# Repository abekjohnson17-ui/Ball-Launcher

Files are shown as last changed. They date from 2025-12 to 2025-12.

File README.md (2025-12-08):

Ping Pong Ball Launcher

What does it do?

This project is a ball launcher that has a closed-loop feedback system. There are three main things that the project does:
1. Calculate the velocity after each shot to dial in the accuracy on the next shot.
2. Often times ping pong can have a wide variety of spin on the ball, this machine can change the spin of the ball at launch.
3. Randomly decide where the next shot will be from left to right.

Motivation:

I am an avid tennis player and a student at the University at Buffalo studying Mechanical Engineering. I wanted to make a tennis ball launcher but the motors and components would be out of my budget, so I decided to scale it down to a ping pong ball launcher. 
I have used tennis ball launchers before and one thing that they can do is they can put variable spin on the ball to simulate a real game. This is a major feature I want to encorporate into my project. Essentially, the two robots are the same just scaled differently.

BOM:



Link to BOM: 

https://docs.google.com/spreadsheets/d/1TKzZSILnyTzFo4eQHcQ44TPMbz68pp8OG-lISy_ujTU/edit?gid=0#gid=0

STL Files are located under the src folder -> STL Files

Wiring:



What is Each Part Responsible for?
- 12V MAX 300 RPM DC Motors >> Spin the wheels to launch the balls.
- 6V MAX 5 RPM DC Motors >> Spin auger feeding mechanism.
- 20KG Servo Motor >> Turn machine left to right.
- Hall Effect Sensors >> Used to determine spin and RPM of motors.
- Laser Reciever Sensors >> Used to calculate exit velocity of the ball and make the next shot more accurate.
- L293D Motor Driver >> Allows for variable speed control of the motors.

Limitations:

1. The motors do not spin fast enough to launch the ball at a decent distance, I should have used motors that spin at much higher RPM. To get around this with what I had I used a gear ratio to increase speed.
2. The auger feeding mechanism will drop 2-3 balls at a time. To fix this I can add dividers along the length of the auger to drop one ball at a time.
3. The servo that turns the machine from left to right will jam sometimes. I should have made the attachment system more aligned with the axis.

Pictures:







Link to YouTube Video of Velocity Calculation Demo:

[https://studio.youtube.com/video/sxxTJT0Kazk/edit](https://youtube.com/shorts/sxxTJT0Kazk)

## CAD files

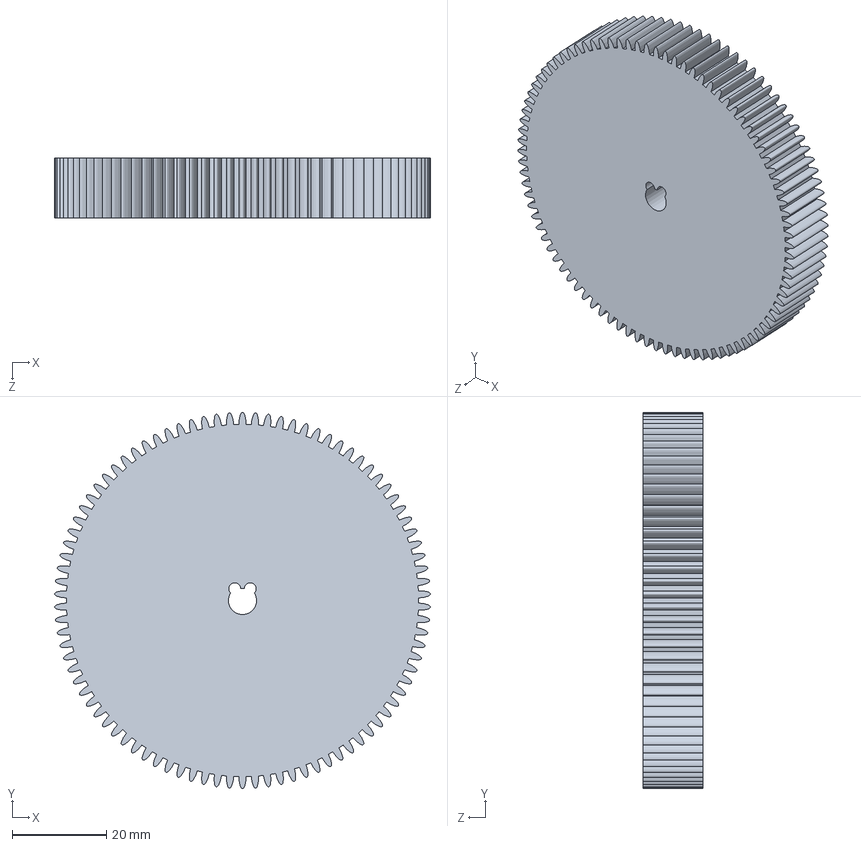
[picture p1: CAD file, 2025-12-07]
src/STL Files/MAE476 PROJECT V2/GEARBOTTOM.SLDPRT
80.0 x 80.0 x 12.7 mm

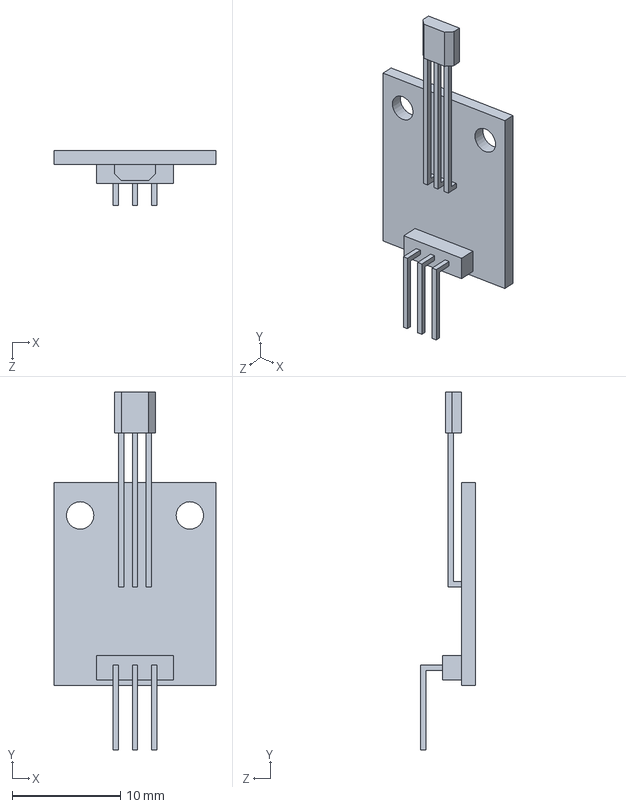
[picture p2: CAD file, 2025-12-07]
src/STL Files/MAE476 Project/HALLEFFECT.SLDPRT
15.0 x 33.1 x 5.08 mm

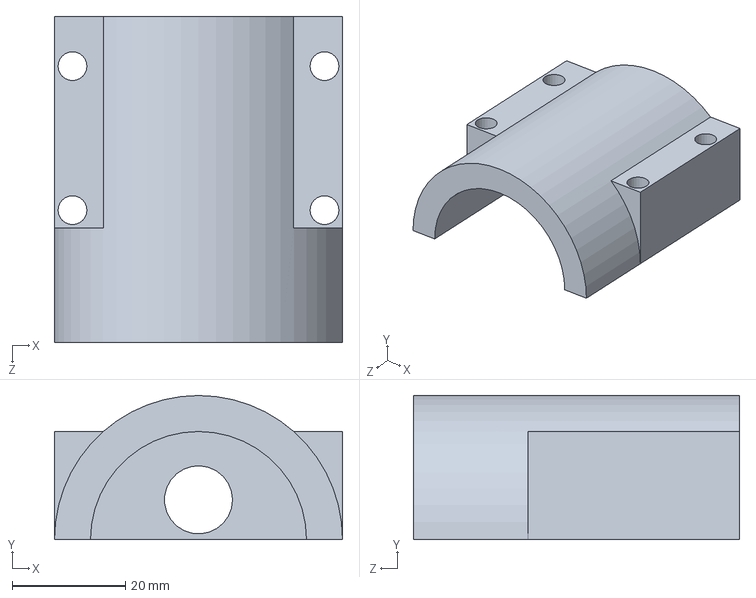
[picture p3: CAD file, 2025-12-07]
src/STL Files/MAE476 PROJECT V2/12VMOUNT.SLDPRT
50.8 x 25.4 x 57.6 mm

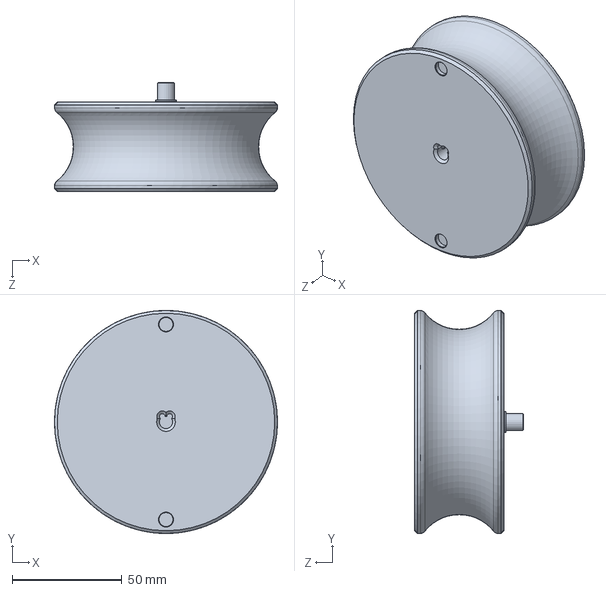
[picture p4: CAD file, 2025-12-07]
src/STL Files/MAE476 Project/WHEEL.SLDPRT
101.6 x 101.6 x 49.5 mm

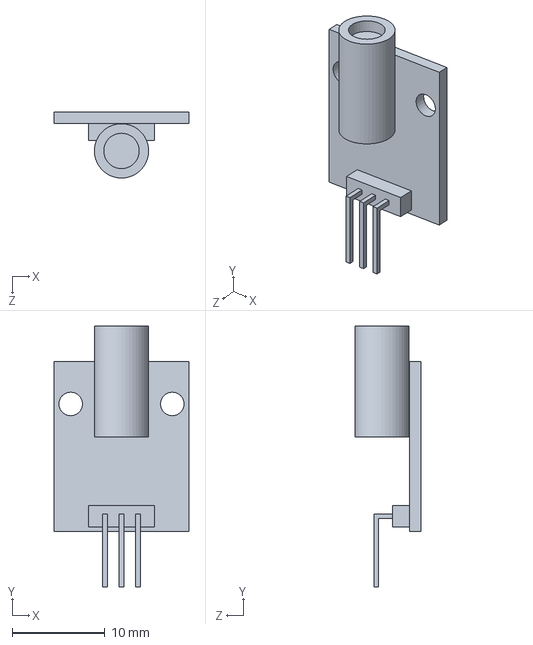
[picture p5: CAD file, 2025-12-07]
src/STL Files/MAE476 Project/LAZEREMITTER.SLDPRT
14.5 x 28.1 x 7.11 mm

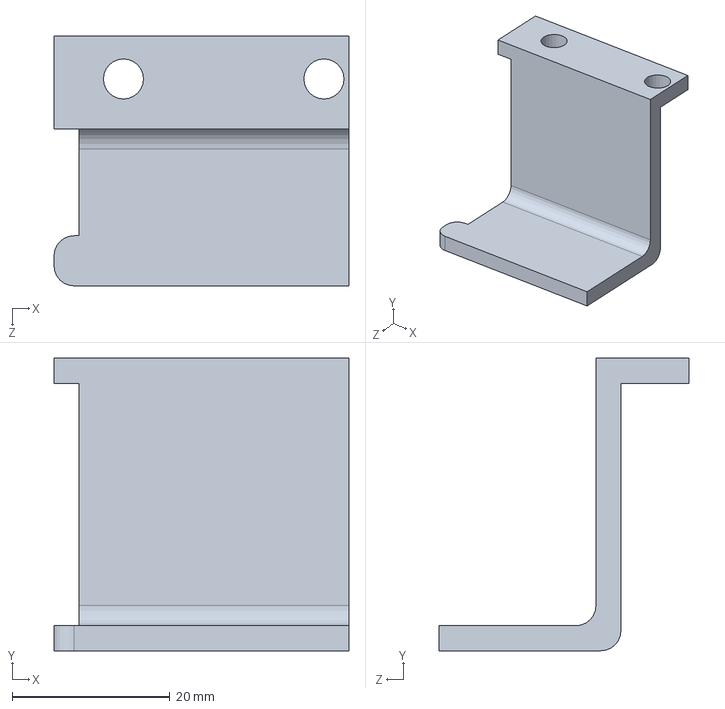
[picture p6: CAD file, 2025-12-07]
src/STL Files/MAE476 PROJECT V2/GEARHOLDER.SLDPRT
37.4 x 37.1 x 31.6 mm

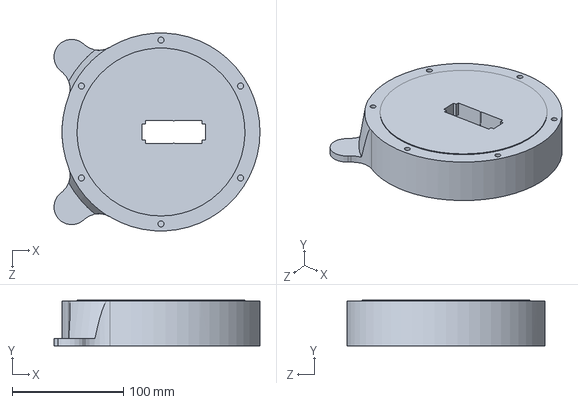
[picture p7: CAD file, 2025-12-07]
src/STL Files/MAE476 Project/BASE.SLDPRT
185.0 x 40.9 x 177.6 mm

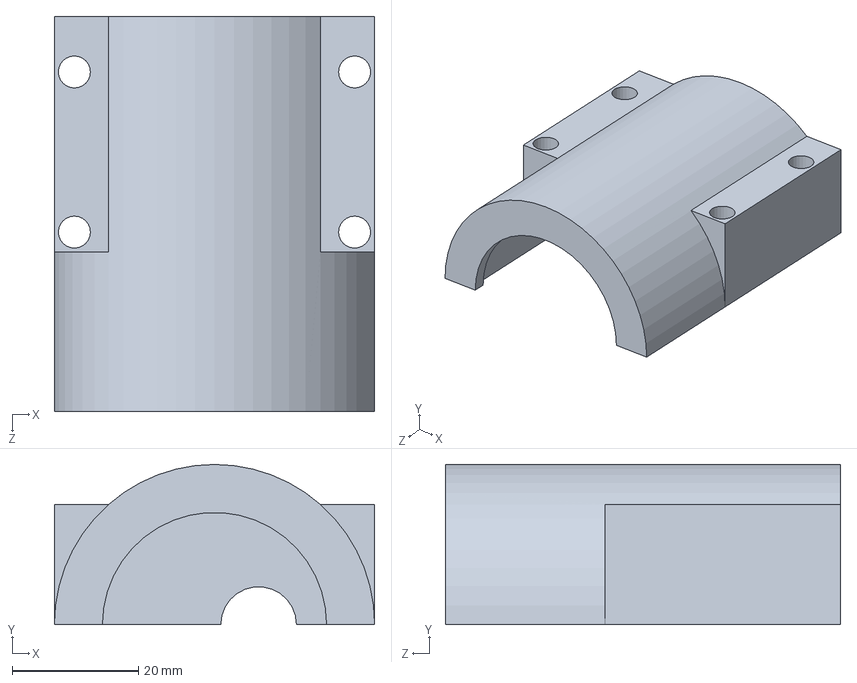
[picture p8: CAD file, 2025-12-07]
src/STL Files/MAE476 PROJECT V2/12VMOUNT2.SLDPRT
50.8 x 25.4 x 62.7 mm

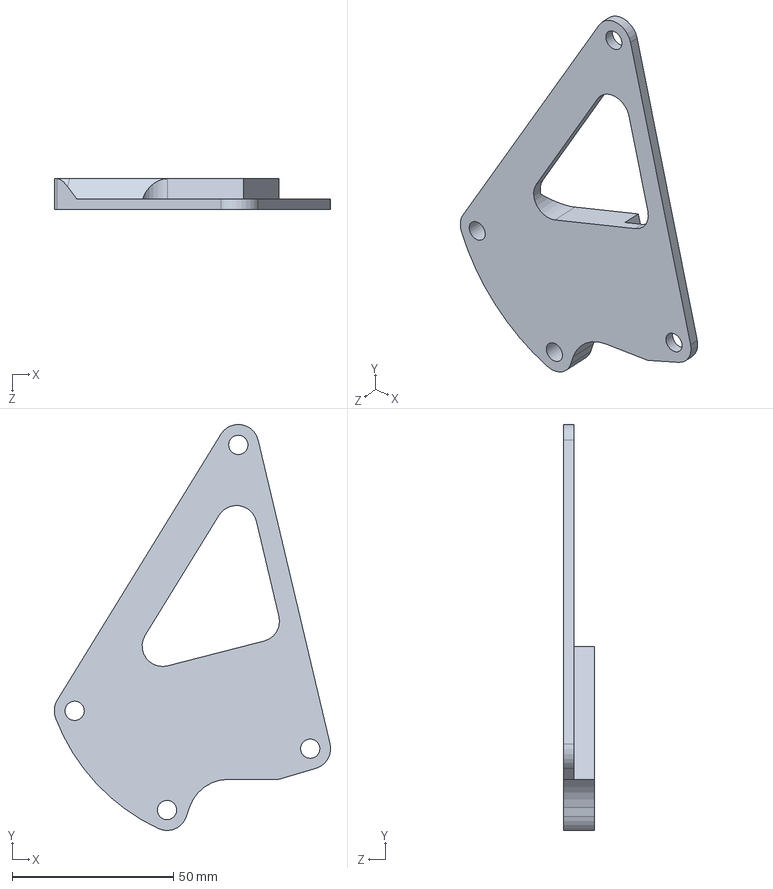
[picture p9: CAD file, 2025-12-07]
src/STL Files/MAE476 Project/TRACKARMS.SLDPRT
85.8 x 126.0 x 9.55 mm

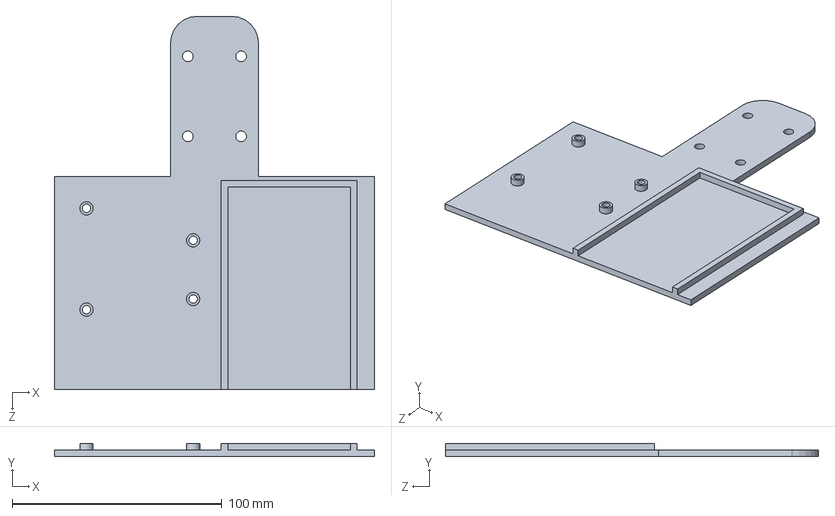
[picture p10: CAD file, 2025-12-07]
src/STL Files/MAE476 PROJECT V2/ELECTRONICS.SLDPRT
152.4 x 6.35 x 177.8 mm

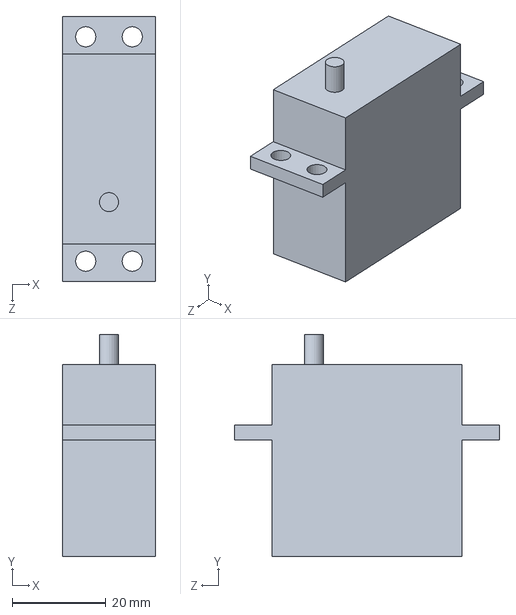
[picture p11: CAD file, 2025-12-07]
src/STL Files/MAE476 Project/SERVO.SLDPRT
19.8 x 47.2 x 56.4 mm

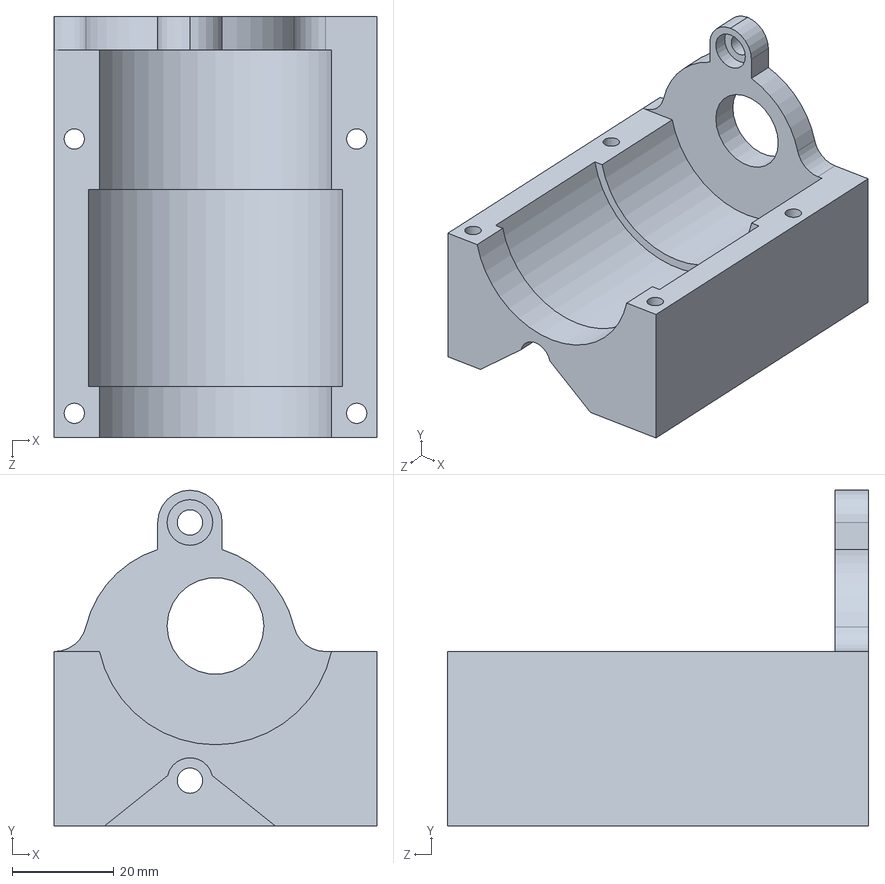
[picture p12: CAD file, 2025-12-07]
src/STL Files/MAE476 PROJECT V2/MOTORMOUNT3.SLDPRT
63.5 x 66.0 x 82.8 mm

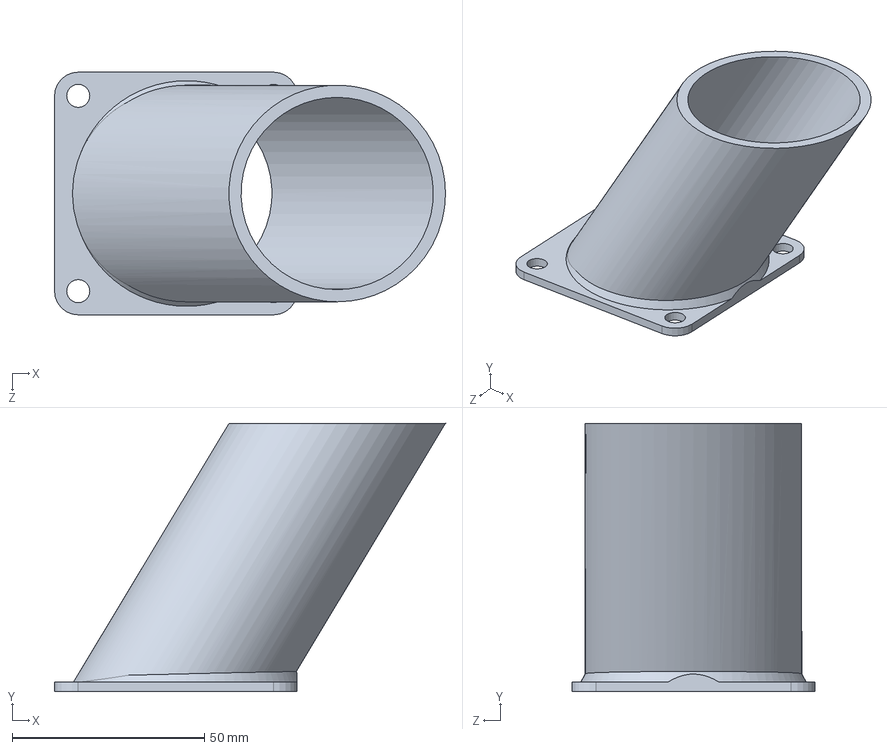
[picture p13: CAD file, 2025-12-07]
src/STL Files/MAE476 Project/CHUTE.SLDPRT
101.7 x 69.8 x 63.2 mm

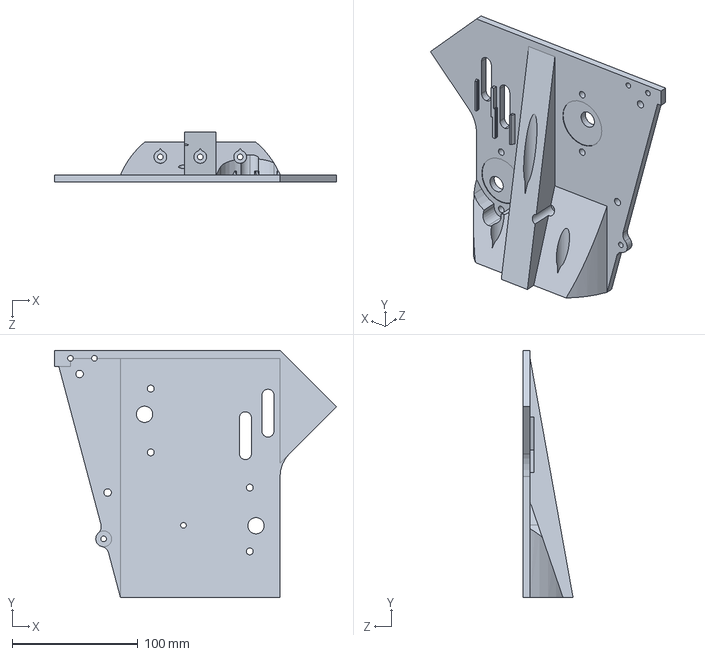
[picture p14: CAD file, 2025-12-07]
src/STL Files/MAE476 PROJECT V2/TURRETRIGHT.SLDPRT
224.4 x 196.9 x 40.0 mm

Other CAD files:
src/STL Files/MAE476 PROJECT V2/ASSYV2.SLDASM
src/STL Files/MAE476 PROJECT V2/ASSY.SLDASM
src/STL Files/MAE476 Project/ASSY.SLDASM
src/STL Files/MAE476 Project/MOTORMOUNT2.SLDPRT
src/STL Files/MAE476 PROJECT V2/12VMOUNT.STL
src/STL Files/MAE476 PROJECT V2/12VMOUNT2.STL
src/STL Files/MAE476 PROJECT V2/AUGER.SLDPRT
src/STL Files/MAE476 PROJECT V2/AUGER.STL
src/STL Files/MAE476 PROJECT V2/AUGERTRAY.3mf
src/STL Files/MAE476 PROJECT V2/AUGERTRAY.SLDPRT
src/STL Files/MAE476 PROJECT V2/AUGERTRAY.STL
src/STL Files/MAE476 PROJECT V2/BALL.SLDPRT
src/STL Files/MAE476 PROJECT V2/BASE.3mf
src/STL Files/MAE476 PROJECT V2/BASE.STL
src/STL Files/MAE476 PROJECT V2/BASETOP.SLDPRT
src/STL Files/MAE476 PROJECT V2/BASETOP.STL
src/STL Files/MAE476 PROJECT V2/BEARING.SLDPRT
src/STL Files/MAE476 PROJECT V2/BUCKET.SLDPRT
src/STL Files/MAE476 PROJECT V2/BUCKET.STL
src/STL Files/MAE476 PROJECT V2/CHUTE.STL
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

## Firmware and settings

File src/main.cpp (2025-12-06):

https://github.com/abekjohnson17-ui/Ball-Launcher.git
#include <Arduino.h>

// Target Velocity
float targetVelocity_m_s = 2.0;

// Motor Speeds
const int MOTOR_MAX = 255;
const int MOTOR_HALF = MOTOR_MAX / 2;

// Globals
int currentWheelMotorSpeed = MOTOR_MAX;
float currentVelocity_m_s = 0.0;

// Laser Sensor variables
const float DISTANCE_CM = 2.54;  // distance between sensors
const int SENSOR1 = 2;  // first trip sensor
const int SENSOR2 = 3;  // second trip sensor
volatile unsigned long timeA = 0;
volatile unsigned long timeB = 0;
volatile bool triggeredA = false;
volatile bool triggeredB = false;

// Servo
const int servoPin = 13;

// Motor 1 (Bottom Wheel) pins
const int EN1 = 9;
const int IN1 = 8;
const int IN2 = 7;

// Motor 2 (Top Wheel) pins
const int EN2 = 6;
const int IN3 = 5;
const int IN4 = 4;

// Motor 3 (Feeder) pins
const int EN3 = 10;
const int IN5 = 11;
const int IN6 = 12;

void sensorA_ISR() {
  if (!triggeredA) {
    timeA = micros();
    triggeredA = true;
  }
  Serial.println("Sensor A Triggered!");
}

void sensorB_ISR() {
  if (!triggeredB) {
    timeB = micros();
    triggeredB = true;
  }
  Serial.println("Sensor B Triggered!");
}


float calculateVelocity() {
  unsigned long dt = timeB - timeA;  // microseconds
  float seconds = dt / 1e6;          // convert to seconds

  float velocity_cm_s = DISTANCE_CM / seconds;
  float velocity_m_s  = velocity_cm_s / 100.0;

  // Reset for next object
  triggeredA = false;
  triggeredB = false;

  return velocity_m_s;
}

// Setup motor pins
void setupMotor(int en, int in1, int in2) {
  pinMode(en, OUTPUT);
  pinMode(in1, OUTPUT);
  pinMode(in2, OUTPUT);
}

void setupLaserSensors() {
  pinMode(SENSOR1, INPUT_PULLUP);
  pinMode(SENSOR2, INPUT_PULLUP);

  attachInterrupt(digitalPinToInterrupt(SENSOR1), sensorA_ISR, FALLING); // Found online https://docs.arduino.cc/language-reference/en/functions/external-interrupts/attachInterrupt/
  attachInterrupt(digitalPinToInterrupt(SENSOR2), sensorB_ISR, FALLING); // attachInterrupt(digitalPinToInterrupt(pin), ISR, mode)
}  // the ISR to call when the interrupt occurs; this function must take no parameters and return nothing. This function is sometimes referred to as an interrupt service routine.

void setMotorSpeed(int en, int speed) {
  // Constrain speed to valid PWM range
  speed = constrain(speed, 0, 255);

  // Apply PWM duty cycle to enable pin
  analogWrite(en, speed);

  // Print statements
  Serial.print("Speed of pin ");
  Serial.print(en);
  Serial.print(": ");
  Serial.println(speed);
}

void setWheelSpeeds(int speed, int spin) {
  int motor1_speed = speed; 
  int motor2_speed = speed;

  // Back-Spin 
  if (spin < 0) {
    motor2_speed = speed + spin;
    motor2_speed = constrain(motor2_speed, 0, 255);
  }
  // Top-Spin
  else if (spin > 0) {
    motor1_speed = speed + spin;
    motor1_speed = constrain(motor2_speed, 0, 255);
  }
  // Else spin = 0: both motors same speed

  // Apply Motor Speeds accounting for spin
  setMotorSpeed(EN1, motor1_speed);
  setMotorSpeed(EN2, motor2_speed);
}

void setupMotorDirections() {
    // Motor 1
    digitalWrite(IN1, HIGH);
    digitalWrite(IN2, LOW);
    // Motor 2
    digitalWrite(IN3, HIGH);
    digitalWrite(IN4, LOW);
    // Motor 3
    digitalWrite(IN5, HIGH);
    digitalWrite(IN6, LOW);
}

void dropBall () {
  // Turns motor at max speed for 15s
  digitalWrite(EN3, HIGH);

  delay(20000);

  digitalWrite(EN3, LOW);
}

void setup() {
  // Initialize serial terminal
  Serial.begin(9600);
  
  // Setup random seed to randomize servo direction
  randomSeed(analogRead(0)); // reads noise on pin 0 which gives random number (Found Online: https://forum.arduino.cc/t/randomseed-analogread-0/109478)

  // Setup Servo pwm pin
  pinMode(servoPin, OUTPUT);

  // Setup Motor Pins
  setupMotor(EN1, IN1, IN2);
  setupMotor(EN2, IN3, IN4);
  setupMotor(EN3, IN5, IN6);

  // Setup Motor directions using H-bridge (L293d) inputs
  setupMotorDirections();

  // Setup Laser pins for interrupts
  setupLaserSensors();

  Serial.println("Motors initialized.");

}

void loop() {
  setWheelSpeeds(currentWheelMotorSpeed, 0);
  
  // dropBall(); // Comment out if not working

  // Waits until the lazers are tripped
  while (triggeredA == 0 || triggeredB == 0); // Wait for both sensors to trip

  currentVelocity_m_s = calculateVelocity();
 
  Serial.print("Velocity: ");
  Serial.print(currentVelocity_m_s);
  Serial.println("m/s");

  float targetCurrentVelocityRatio = targetVelocity_m_s / currentVelocity_m_s;

  // Current < target : ratio < 1
  if (targetCurrentVelocityRatio != 1) {
    currentWheelMotorSpeed = constrain(currentWheelMotorSpeed * targetCurrentVelocityRatio, 0, 255);
  }
}
